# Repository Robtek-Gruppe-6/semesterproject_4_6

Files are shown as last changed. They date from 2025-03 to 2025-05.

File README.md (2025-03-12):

# Control of Pan Tilt System Group 6 (4) ROBTEK Semester 4 SDU
The goal is to control a Pan-Tilt System using an FPGA and a Microcontroller to track heat/IR from an IR emitting moving object.

## FPGA
To setup the FPGA, go to the FPGA folder and check the README.md file there.

## Microcontroller
To setup the Microcontroller, go to the Microcontroller folder and check the README.md file there.
Information about the microcontroller goes here.

## Inventor
To setup Inventor, go to the Inventor folder and check the README.md file there.

## Code explanation

## Resources

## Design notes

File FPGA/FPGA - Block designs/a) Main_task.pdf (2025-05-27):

FPGA_Encoder_handler_1 FPGA_Encoder_handler.bd a

bclk position[14:0] max enrst FPGA_Encoder_handler_2 FPGA_Encoder_handler.bd a bclk position[14:0] max enrst FPGA_Motor_handler_1 FPGA_Motor_handler.bd i[10:0] clk rst o[1:0] en FPGA_Motor_handler_2 FPGA_Motor_handler.bd i[10:0] clk o[1:0] enrst FPGA_SPI_handler_0 FPGA_SPI_handler.bd encoder1[14:0] encoder2[14:0] sck ssmosi enrst miso motor1[10:0] motor2[10:0] clk always_high Constant dout[0:0]

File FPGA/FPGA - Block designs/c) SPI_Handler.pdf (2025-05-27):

encoder2[14:0] clk encoder1[14:0] rst en sckss mosi not_gate_0 not_gate_v1_0 i o encoder_latch2 dlatch_v1_0 clk i[14:0] enrst o[14:0] encoder_latch1 dlatch_v1_0 clk i[14:0] enrst o[14:0] encoder_selctor d_flip_flop_v1_0 clk D Q enrst encoder_selector_mux busmux_2x1_v1_0 input_1[14:0] input_2[14:0] s o[14:0] selector_combine combiner_v1_0 h[0:0] l[14:0] o[15:0] xlconstant_0 Constant dout[0:0] SPI_slave_block cpol cpha sck ssmosi SPI_slave_block_v1_0 miso read_en tx[15:0] rx[15:0] busy rst selector_split i[15:0] n_to_m_splitter_v1_0 o_h[0:0] o_l[10:0] motor_selector busdmux_v1_0 clk endata_in[10:0] sel[0:0] rst data_out_1[10:0] data_out_2[10:0] miso motor1[10:0] motor2[10:0]

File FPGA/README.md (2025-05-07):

# Vivado setup
Use Xilinx Vivado to create a vivado project in this directory.
Name the project "vivado_project", this will make git ignore the project folder, and only update sources and block designs.

Make sure that when you create a new ip/block design, that the file location is the sources or block_design directory. 

Any .bit in this folder are tested binaries ready to be transfered onto the PYNQ-Z2 board

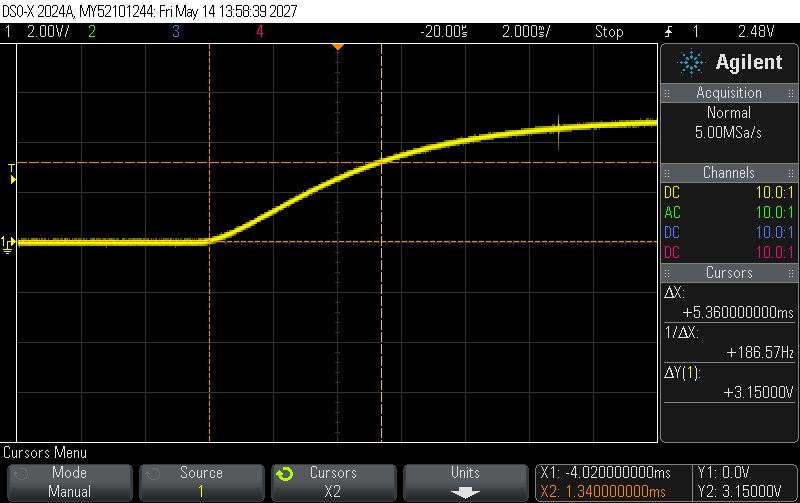
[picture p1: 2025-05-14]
Time_constant_tilt.png

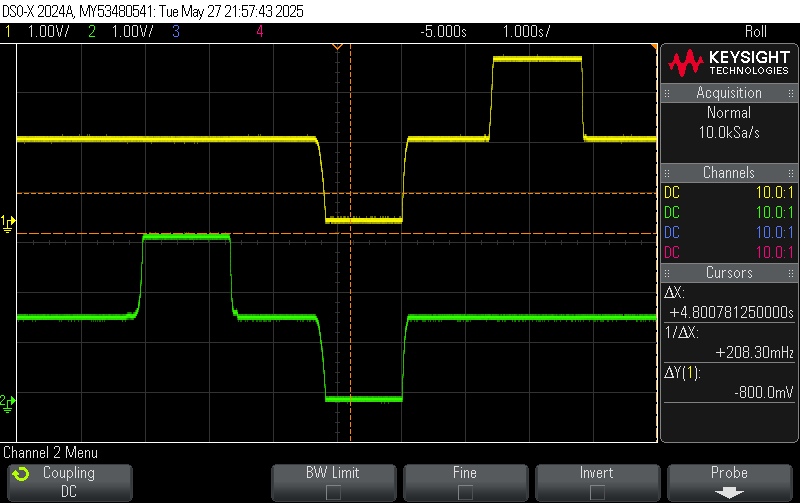
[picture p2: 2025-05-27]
Matlab/oscilloscope/Sensor_circuit.png

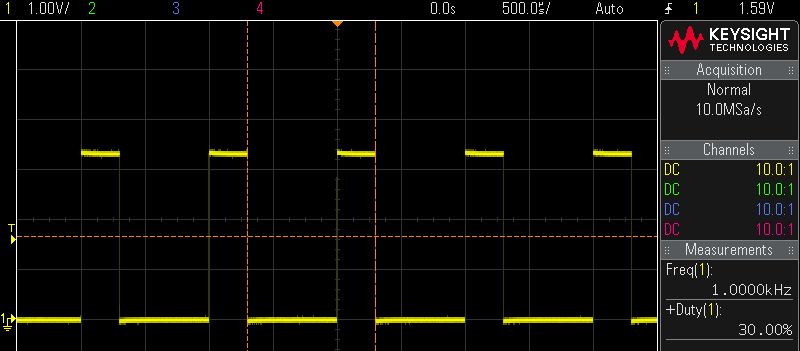
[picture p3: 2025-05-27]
Matlab/oscilloscope/PWM.png

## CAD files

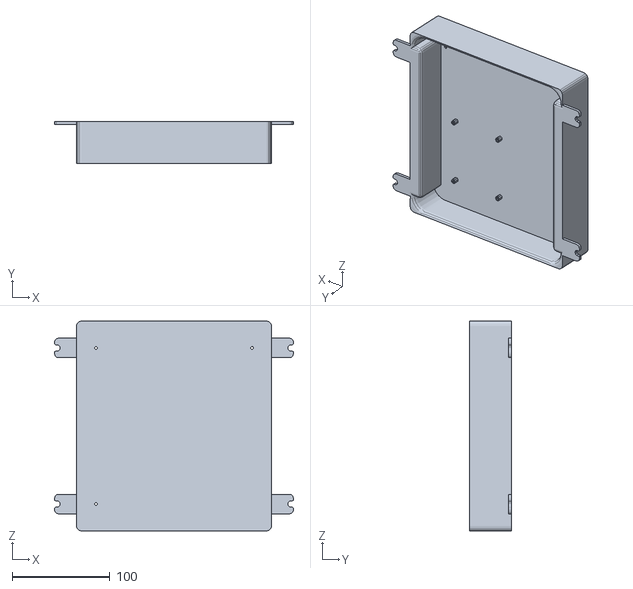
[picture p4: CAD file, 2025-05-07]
Inventor/Infrared_collector.stl
245.0 x 43.0 x 215.0

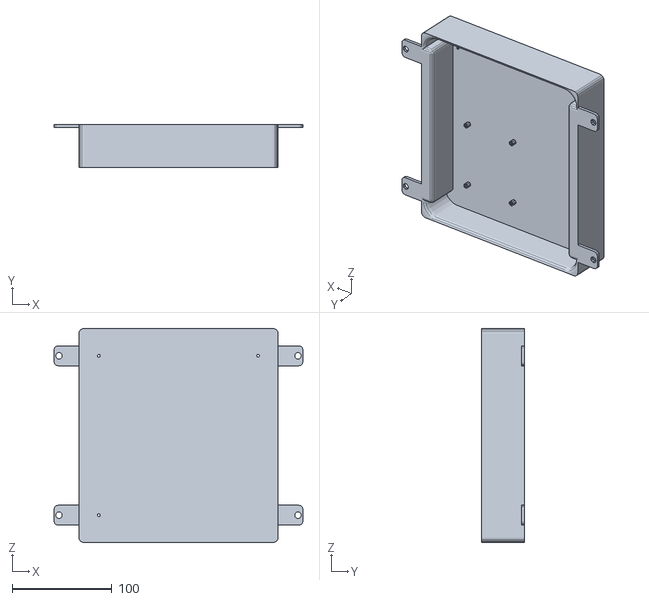
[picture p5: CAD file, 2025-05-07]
Inventor/Infrared_collector_long_ear.stl
250.0 x 43.0 x 215.0

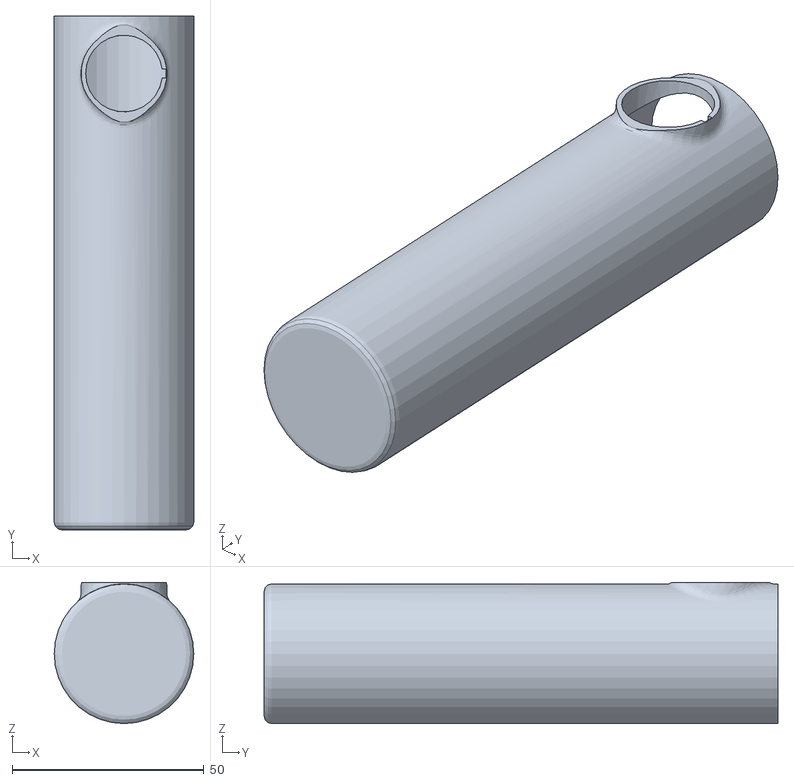
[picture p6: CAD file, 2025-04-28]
Inventor/Flash_light.stl
36.4 x 134.0 x 36.8

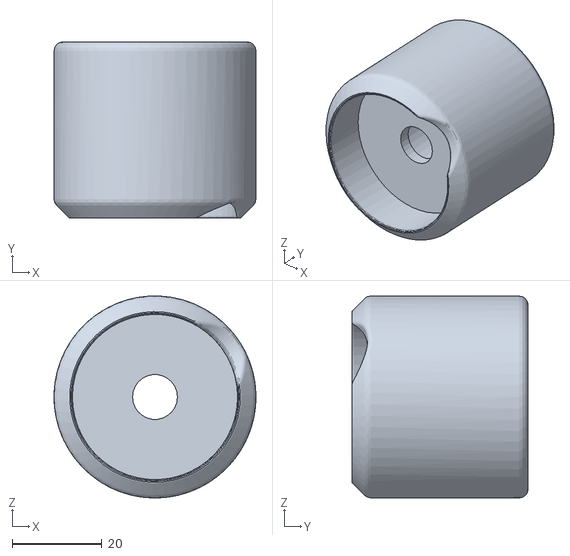
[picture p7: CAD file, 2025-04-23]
Inventor/Flashlight_lid.stl
45.0 x 39.3 x 45.0

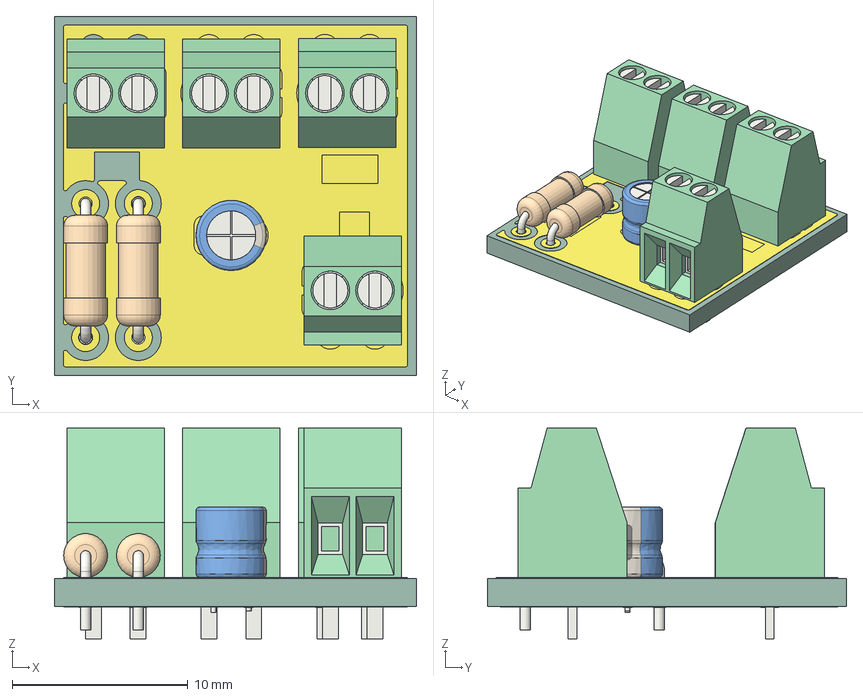
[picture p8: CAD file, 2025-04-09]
Inventor/fleshlight_pcb.step
20.6 x 20.4 x 12.0 mm
R_Axial_DIN0207_L63mm_D25mm_P762mm_Horizontal x 2
TerminalBlock_Phoenix_MPT_05_2_254_1x02_P254mm_Horizontal x 4
CP_Radial_D40mm_P200mm
_autosave-fleshlight_track_1
_autosave-fleshlight_track_2
_autosave-fleshlight_track_3
_autosave-fleshlight_track_4
_autosave-fleshlight_track_5
_autosave-fleshlight_track_6
_autosave-fleshlight_track_7
_autosave-fleshlight_track_8
_autosave-fleshlight_track_9
_autosave-fleshlight_track_10
_autosave-fleshlight_track_11
_autosave-fleshlight_track_12
_autosave-fleshlight_track_13
_autosave-fleshlight_track_14
_autosave-fleshlight_track_15
_autosave-fleshlight_track_16
_autosave-fleshlight_track_17
_autosave-fleshlight_track_18
_autosave-fleshlight_track_19
_autosave-fleshlight_track_20
_autosave-fleshlight_track_21
_autosave-fleshlight_track_22
_autosave-fleshlight_track_23
_autosave-fleshlight_track_24
_autosave-fleshlight_track_25
_autosave-fleshlight_track_26
_autosave-fleshlight_zone_1
_autosave-fleshlight_zone_2
_autosave-fleshlight_pad_1
_autosave-fleshlight_pad_2
_autosave-fleshlight_pad_3
_autosave-fleshlight_pad_4
_autosave-fleshlight_pad_5
_autosave-fleshlight_pad_6
_autosave-fleshlight_pad_7
_autosave-fleshlight_pad_8
_autosave-fleshlight_pad_9
_autosave-fleshlight_pad_10
_autosave-fleshlight_pad_11
_autosave-fleshlight_pad_12
_autosave-fleshlight_pad_13
_autosave-fleshlight_pad_14
_autosave-fleshlight_pad_15
_autosave-fleshlight_pad_16
_autosave-fleshlight_pad_17
_autosave-fleshlight_pad_18
_autosave-fleshlight_pad_19
_autosave-fleshlight_pad_20
_autosave-fleshlight_pad_21
_autosave-fleshlight_pad_22
_autosave-fleshlight_pad_23
_autosave-fleshlight_pad_24
_autosave-fleshlight_pad_25
_autosave-fleshlight_pad_26
_autosave-fleshlight_pad_27
_autosave-fleshlight_pad_28
_autosave-fleshlight_pad_29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

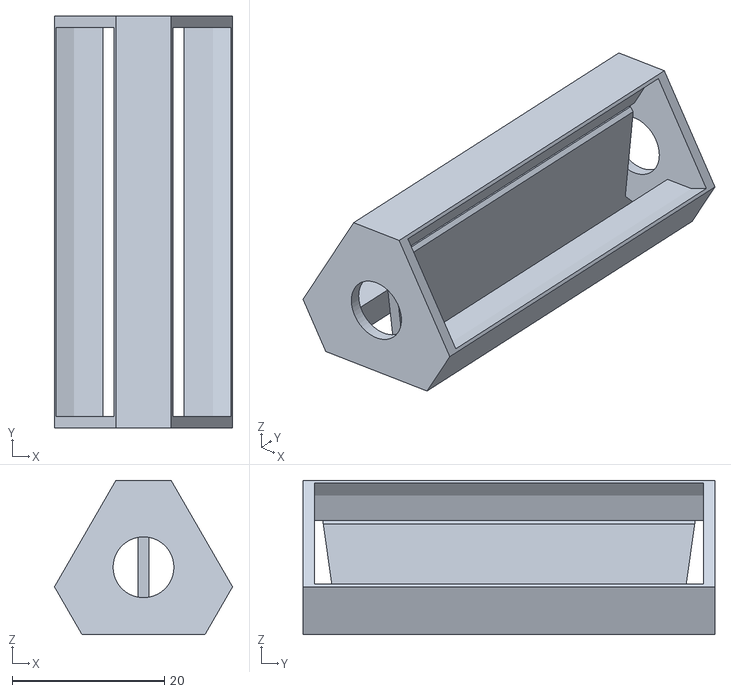
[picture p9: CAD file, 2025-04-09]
Inventor/Battery_Holder_3AA_V1.stl
23.4 x 54.2 x 20.3

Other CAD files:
Inventor/161130345-9-xb-rs601c-1020011bb-zp/xb-rs601c-1020011bb-zp.iam
Inventor/161130345-9-xb-rs601c-1020011bb-zp/xb-rs601c-1020011bb-zp_01.ipt
Inventor/161130345-9-xb-rs601c-1020011bb-zp/xb-rs601c-1020011bb-zp_02.ipt
Inventor/161130345-9-xb-rs601c-1020011bb-zp/xb-rs601c-1020011bb-zp_03.ipt
Inventor/161130345-9-xb-rs601c-1020011bb-zp/xb-rs601c-1020011bb-zp_04.ipt
Inventor/161130345-9-xb-rs601c-1020011bb-zp/xb-rs601c-1020011bb-zp_05.ipt
Inventor/161130345-9-xb-rs601c-1020011bb-zp/xb-rs601c-1020011bb-zp_06.ipt
Inventor/Flash_light.ipt
Inventor/Flashlight.iam
Inventor/Flashlight_lid.ipt
Inventor/Infrared_collector.ipt
Inventor/OldVersions/Flash_light.0004.ipt
Inventor/OldVersions/Flashlight.0006.iam
Inventor/OldVersions/Flashlight_lid.0007.ipt
Inventor/OldVersions/Infrared_collector.0007.ipt
Inventor/fleshlight.ipt
Inventor/fleshlight_pcb/CP_Radial_D4.0mm_P2.00mm.iam
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

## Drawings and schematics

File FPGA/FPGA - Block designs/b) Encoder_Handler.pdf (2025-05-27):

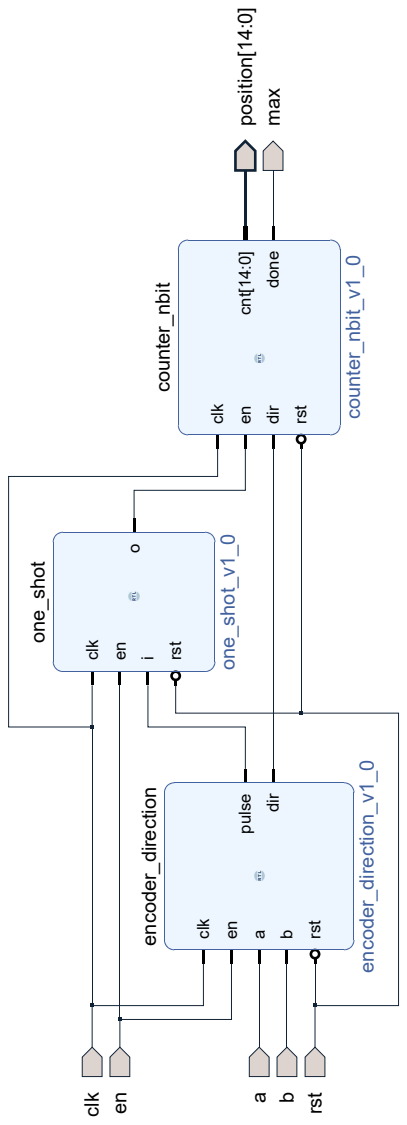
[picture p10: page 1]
clkena; irst

o counter_nbit counter_nbit_v1_0 cnt[14:0] done clk endir rst position[14:0] max

brst pulsedir one_shot one_shot_v1_0 clk en

brst encoder_direction encoder_direction_v1_0 clk en

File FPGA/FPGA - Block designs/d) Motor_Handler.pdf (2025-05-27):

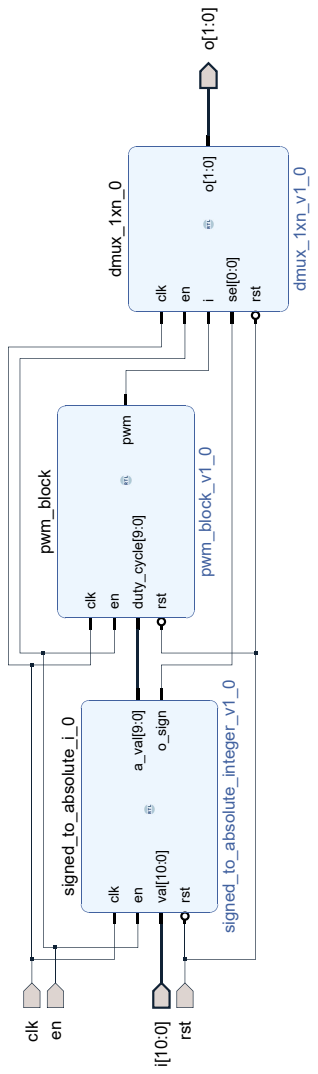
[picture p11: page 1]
isel[0:0] rst o[1:0] o[1:0]

clken i[10:0] rst signed_to_absolute_i_0 signed_to_absolute_integer_v1_0 clk enval[10:0] a_val[9:0] o_sign rst pwm_block pwm_block_v1_0 clk enduty_cycle[9:0] rst pwm dmux_1xn_0 dmux_1xn_v1_0 clk en

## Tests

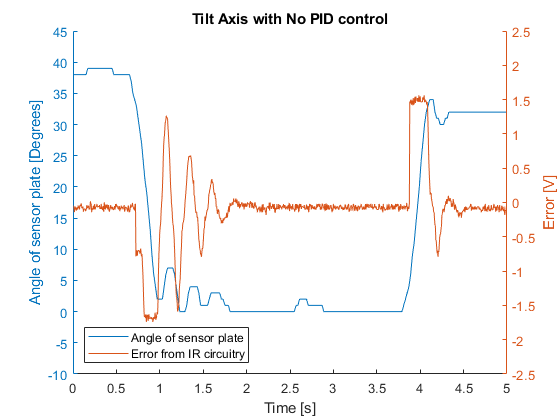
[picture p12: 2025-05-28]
Matlab/pid_tests/tilt_nopid.png

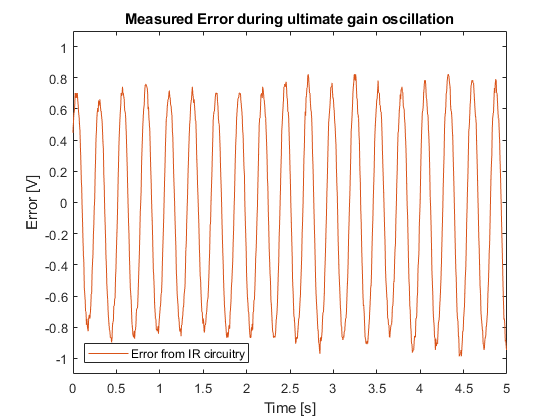
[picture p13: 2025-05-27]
Matlab/pid_tests/ultimate_gain.png

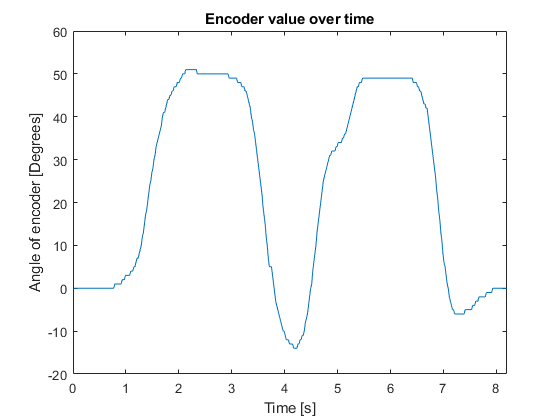
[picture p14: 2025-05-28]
Matlab/pid_tests/encoder_test.png

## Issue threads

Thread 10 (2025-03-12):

Emitterkredsløb

spkki, 2025-03-12:
Magnus laver lommelygte

Svend tegner noget 3d print på et tidspunkt

Emitter kredsløb er ellers done

Lommelygte values:
- Voltage: 4.5V (triple AA battery setup)
- Current: 100mA
- Resistance: 15Ohm

Closed 2025-03-26.

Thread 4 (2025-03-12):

Programmer encoder decoding

spkki, 2025-03-12:

Teh-Faber, 2025-03-19:
Output is represented as degrees per second a fixed point number (Q11.5 number format) where max velocity is 2048 and precision is 6.25% of a degree per second

spkki, 2025-03-19:
We have tested but it doesn't work as there is some kind of problem with dividing in the velocity calculation...

Closed 2025-03-26.

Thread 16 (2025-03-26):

ADC kredsløb

spkki, 2025-03-26:

PapaEchoRomeo, 2025-04-09:
Tested using the led.
Picture 1: When both acd readings are under 1,65 (which is offset to 0) the led is blue.
Picture 2: When one of the adc readings are above 1,65 the led ia purple.
Picture 3: When both adc readings are over 1,65 the led is red.
The adc readings are offset and scaled to return values from -32000 to 32000 :)

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

Closed 2025-05-02.

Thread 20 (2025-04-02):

FPGA arkitektur

spkki, 2025-04-02:

spkki, 2025-04-02:
Vi har lavet motor handler og testet den

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

se 60% duty cycle i en retning og modsat 40% i den anden retning

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

Teh-Faber, 2025-04-09:
SPI Handler finished and integrated into the overall design. Not yet tested

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

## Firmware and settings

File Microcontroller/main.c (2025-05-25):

/*****************************************************************************
 * University of Southern Denmark
 * Embedded C Programming (ECP)
 *
 * MODULENAME.: main.c
 *
 * PROJECT....: SEMESTERPROJECT
 *
 * DESCRIPTION:
 *
 * Change Log:
 ******************************************************************************
 * Date    Id    Change
 * YYMMDD
 * --------------------
 * 250502  SBT    Module created.
 *
 *****************************************************************************/

/***************************** Include files ********************************/
#include <stdint.h>
#include <stdlib.h>
#include "tm4c123gh6pm.h"
#include "emp_type.h"
#include "systick_frt.h"
#include "FreeRTOS.h"
#include "task.h"
#include "queue.h"
#include "semphr.h"

#include "status_led.h"
#include "adc.h"
#include "spi.h"
#include "shared_resources.h"
#include "uart.h"

/*****************************    Defines    ********************************/
#define USERTASK_STACK_SIZE (configMINIMAL_STACK_SIZE * 4) // Increase stack size
#define IDLE_PRIO 0
#define LOW_PRIO 1
#define MED_PRIO 2
#define HIGH_PRIO 3

/*****************************   Constants   ********************************/

/*****************************   Variables   ********************************/

/*****************************   Functions   ********************************/
static void setupHardware(void)
/*****************************************************************************
 *  Input    :  -
 *  Output   :  -
 * *  Function :  Set up the hardware for the project.
 ******************************************************************************/
{
    // Set up the hardware here (GPIO, UART, etc.)
    // Do we need to set up the system clock like in previous project now that it is ignored?
    init_systick();    // Initialize the systick timer
    status_led_init(); // Initialize the status LED
    UART0_Init();
    adc_init(); // Initialize the ADCs
    ADC0_Init();
    SPI0_init(); // Initialize the SPI interface
}

int main(void)
/*****************************************************************************
 * *  Input    :    -
 * *  Output   :    -
 * *  Function :  Main function for the project.
 * ******************************************************************************/
{

    setupHardware(); // Set up the hardware

    TaskResources_t *resources = pvPortMalloc(sizeof(TaskResources_t));

    resources->spi_rx_queue = xQueueCreate(32, sizeof(uint16_t));
    resources->spi_tx_queue = xQueueCreate(32, sizeof(uint16_t));
    resources->adc0_queue = xQueueCreate(32, sizeof(uint16_t));
    resources->adc1_queue = xQueueCreate(32, sizeof(uint16_t));
    resources->spi_mutex = xSemaphoreCreateMutex();

    // xTaskCreate(status_led_task, "Status LED",      USERTASK_STACK_SIZE, (void *) resources, LOW_PRIO, NULL);
    xTaskCreate(adc_task, "ADC Task", USERTASK_STACK_SIZE, (void *)resources, LOW_PRIO, NULL);
    // xTaskCreate(spi_task_read, "SPI Task Read",     USERTASK_STACK_SIZE, (void *) resources, LOW_PRIO, NULL);
    xTaskCreate(spi_task_write, "SPI Task Write", USERTASK_STACK_SIZE, (void *)resources, LOW_PRIO, NULL);
    // xTaskCreate(spi_task_rw, "SPI Task RW",         USERTASK_STACK_SIZE, (void *) resources, LOW_PRIO, NULL);
    // xTaskCreate(SPI_test_task, "SPI Test Task",     USERTASK_STACK_SIZE, (void *) resources, LOW_PRIO, NULL);

    vTaskStartScheduler(); // Start the FreeRTOS scheduler
    // The scheduler should never return, but if it does, we can handle it here
    return 0;
}

/****************************** End Of Module *******************************/

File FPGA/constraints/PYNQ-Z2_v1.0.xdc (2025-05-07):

## This file is a general .xdc for the PYNQ-Z2 board
## To use it in a project:
## - uncomment the lines corresponding to used pins
## - rename the used ports (in each line, after get_ports) according to the top level signal names in the project

## Clock signal 125 MHz

set_property -dict {PACKAGE_PIN H16 IOSTANDARD LVCMOS33} [get_ports clk]
#create_clock -add -name sys_clk_pin -period 8.00 -waveform {0 4} [get_ports { sysclk }];

##Switches

set_property -dict { PACKAGE_PIN M20   IOSTANDARD LVCMOS33 } [get_ports { sw_0 }]; #IO_L7N_T1_AD2N_35 Sch=sw[0]
set_property -dict { PACKAGE_PIN M19   IOSTANDARD LVCMOS33 } [get_ports { sw_1 }]; #IO_L7P_T1_AD2P_35 Sch=sw[1]

##RGB LEDs

#set_property -dict { PACKAGE_PIN L15   IOSTANDARD LVCMOS33 } [get_ports { led4_b }]; #IO_L22N_T3_AD7N_35 Sch=led4_b
#set_property -dict { PACKAGE_PIN G17   IOSTANDARD LVCMOS33 } [get_ports { led4_g }]; #IO_L16P_T2_35 Sch=led4_g
#set_property -dict { PACKAGE_PIN N15   IOSTANDARD LVCMOS33 } [get_ports { led4_r }]; #IO_L21P_T3_DQS_AD14P_35 Sch=led4_r
#set_property -dict { PACKAGE_PIN G14   IOSTANDARD LVCMOS33 } [get_ports { led5_b }]; #IO_0_35 Sch=led5_b
#set_property -dict { PACKAGE_PIN L14   IOSTANDARD LVCMOS33 } [get_ports { led5_g }]; #IO_L22P_T3_AD7P_35 Sch=led5_g
#set_property -dict { PACKAGE_PIN M15   IOSTANDARD LVCMOS33 } [get_ports { led5_r }]; #IO_L23N_T3_35 Sch=led5_r

##LEDs

#set_property -dict { PACKAGE_PIN R14   IOSTANDARD LVCMOS33 } [get_ports { led[0] }]; #IO_L6N_T0_VREF_34 Sch=led[0]
#set_property -dict { PACKAGE_PIN P14   IOSTANDARD LVCMOS33 } [get_ports { led[1] }]; #IO_L6P_T0_34 Sch=led[1]
#set_property -dict { PACKAGE_PIN N16   IOSTANDARD LVCMOS33 } [get_ports { led[2] }]; #IO_L21N_T3_DQS_AD14N_35 Sch=led[2]
#set_property -dict { PACKAGE_PIN M14   IOSTANDARD LVCMOS33 } [get_ports { led[3] }]; #IO_L23P_T3_35 Sch=led[3]

##Buttons

set_property -dict { PACKAGE_PIN D19   IOSTANDARD LVCMOS33 } [get_ports { btn[0] }]; #IO_L4N_T0_35 Sch=btn[1]
set_property -dict { PACKAGE_PIN D20   IOSTANDARD LVCMOS33 } [get_ports { btn[1] }]; #IO_L4N_T0_35 Sch=btn[1]
set_property -dict { PACKAGE_PIN L20   IOSTANDARD LVCMOS33 } [get_ports { btn[2] }]; #IO_L9N_T1_DQS_AD3N_35 Sch=btn[2]
set_property -dict { PACKAGE_PIN L19   IOSTANDARD LVCMOS33 } [get_ports { btn[3] }]; #IO_L9P_T1_DQS_AD3P_35 Sch=btn[3]

##PmodA

#set_property -dict { PACKAGE_PIN Y18   IOSTANDARD LVCMOS33 } [get_ports { hall_index_0 }]; #IO_L17P_T2_34 Sch=ja_p[1]
#set_property -dict { PACKAGE_PIN Y19   IOSTANDARD LVCMOS33 } [get_ports { hall_index_1 }]; #IO_L17N_T2_34 Sch=ja_n[1]
#set_property -dict { PACKAGE_PIN Y16   IOSTANDARD LVCMOS33 } [get_ports { encoder_1b }]; #IO_L7P_T1_34 Sch=ja_p[2]
#set_property -dict { PACKAGE_PIN Y17   IOSTANDARD LVCMOS33 } [get_ports { encoder_1a }]; #IO_L7N_T1_34 Sch=ja_n[2]
#set_property -dict { PACKAGE_PIN U18   IOSTANDARD LVCMOS33 } [get_ports { encoder_2b }]; #IO_L12P_T1_MRCC_34 Sch=ja_p[3]
#set_property -dict { PACKAGE_PIN U19   IOSTANDARD LVCMOS33 } [get_ports { encoder_2a }]; #IO_L12N_T1_MRCC_34 Sch=ja_n[3]
#set_property -dict { PACKAGE_PIN W18   IOSTANDARD LVCMOS33 } [get_ports { ja[6] }]; #IO_L22P_T3_34 Sch=ja_p[4]
#set_property -dict { PACKAGE_PIN W19   IOSTANDARD LVCMOS33 } [get_ports { ja[7] }]; #IO_L22N_T3_34 Sch=ja_n[4]

##PmodB

set_property -dict { PACKAGE_PIN W14   IOSTANDARD LVCMOS33 } [get_ports { motor1[0] }]; #IO_L8P_T1_34 Sch=jb_p[1]
set_property -dict { PACKAGE_PIN Y14   IOSTANDARD LVCMOS33 } [get_ports { motor_en[0] }]; #IO_L8N_T1_34 Sch=jb_n[1]
set_property -dict { PACKAGE_PIN T11   IOSTANDARD LVCMOS33 } [get_ports { motor2[1] }]; #IO_L1P_T0_34 Sch=jb_p[2]
#set_property -dict { PACKAGE_PIN T10   IOSTANDARD LVCMOS33 } [get_ports {  }]; #IO_L1N_T0_34 Sch=jb_n[2]
set_property -dict { PACKAGE_PIN V16   IOSTANDARD LVCMOS33 } [get_ports { motor1[1] }]; #IO_L18P_T2_34 Sch=jb_p[3]
set_property -dict { PACKAGE_PIN W16   IOSTANDARD LVCMOS33 } [get_ports { motor2[0] }]; #IO_L18N_T2_34 Sch=jb_n[3]
set_property -dict { PACKAGE_PIN V12   IOSTANDARD LVCMOS33 } [get_ports { motor_en[1] }]; #IO_L4P_T0_34 Sch=jb_p[4]
#set_property -dict { PACKAGE_PIN W13   IOSTANDARD LVCMOS33 } [get_ports { jb[7] }]; #IO_L4N_T0_34 Sch=jb_n[4]

##Audio

#set_property -dict { PACKAGE_PIN M17   IOSTANDARD LVCMOS33 } [get_ports { adr0 }]; #IO_L8P_T1_AD10P_35 Sch=adr0
#set_property -dict { PACKAGE_PIN M18   IOSTANDARD LVCMOS33 } [get_ports { adr1 }]; #IO_L8N_T1_AD10N_35 Sch=adr1
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

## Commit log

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2025-03-12 First block design
    [design_motor_encoders_motor_encoders_0_0.xml, design_motor_encoders_system_ila_1_0.xml]
2025-03-12 Created VHDL wrapper
    [design_motor_encoders_system_ila_1_0.xml]
2025-03-19 Updated motor encoder block
    Added direction and began velocity calculation.
    [design_motor_encoders_motor_encoders_0_0.xml, design_motor_encoders_sim_clk_gen_0_0.xml, design_motor_encoders_system_ila_1_0.xml]
2025-03-19 Updated motor encoder
    Added multiple new files instead of previously only having one motor encoder file. Combined all the new files into a block design and started testing. Found a issue with scalling.
    [design_motor_encoders_clock_counter_0_0.xml, design_motor_encoders_combiner_0_0.xml, design_motor_encoders_div_gen_0_0.xml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]
2025-03-26 Added ADC tiva microcontroller code
    Added the ADC tiva microcontroller code
2025-03-26 Added electronics circuit
    yup
    [adder-diff-circuit.kicad_sch]
2025-03-26 SPI is worky work
2025-03-26 Functional Encoder and position calculation
    [design_motor_encoders_counter_nbit_0_0.xml, design_motor_encoders_div_gen_0_0.xml, design_motor_encoders_encoder_direction_0_0.xml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]
2025-04-02 Changed structure to handlers
    Removed Eriks shit code and renamed motor encoders block to encoder handler and added two new handlers
    [design_motor_encoders_counter_nbit_0_0.xml, design_motor_encoders_encoder_direction_0_0.xml, design_motor_encoders_one_shot_0_0.xml]
2025-04-02 Motor handler done
    Added constraint file to project and updated it. Motor handler working in simulation. Main task added
    [FPGA_Motor_handler_dmux_1xn_0_0.xml, FPGA_Motor_handler_inst_0_dmux_1xn_0_0.xml, FPGA_Motor_handler_inst_0_pwm_block_0.xml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]
2025-04-02 Made SPI Handler and updated main task
    Made a busdemux as well.
    [FPGA_Motor_handler_inst_0_pwm_block_0.xml, FPGA_Motor_handler_inst_0_signed_to_absolute_i_0_0.xml, FPGA_Motor_handler_inst_1_dmux_1xn_0_0.xml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]
2025-04-02 Update PYNQ-Z2_v1.0.xdc to fix motor pinout
    [PYNQ-Z2_v1.0.xdc]
2025-04-08 Added project files and started design on flashlight
    Added the inventor project files and started making the flashlight design
    [Flash_light.ipt]
2025-04-08 Edited the infrared collector plate
    [Infrared_collector.0001.ipt, Infrared_collector.0002.ipt, Infrared_collector.ipt]
2025-04-09 Spi fpga lagt ind
2025-04-09 doodoo fart
    Added fleshlight
    [fleshlight.ipt]
2025-04-09 Updated FPGA code for SPI Handler
    [FPGA_Motor_handler_dmux_1xn_0_0.xml, FPGA_Motor_handler_pwm_block_0_1.xml, FPGA_Motor_handler_signed_to_absolute_i_0_0.xml]
2025-04-09 Updated flashlight design
    Updated flashlight design
    [Battery_Holder_3AA_V1.stl, Flash_light.0002.ipt, Flash_light.ipt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]
2025-04-09 Updated Flashlight and added lid
    Should be ready for 3d print
    [CP_Radial_D4.0mm_P2.00mm.iam, CP_Radial_D40mm_P200mm.ipt, Flash_light.0002.ipt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]
2025-04-09 Finished SPI Handler
    And integrated into main task. Missing simulation test.
2025-04-10 Fixed SPI TX
    and removed redundant code
2025-04-18 Hurtig tweak rx spi
2025-04-18 Spi rx works skal bare lave en interrupt
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2025-04-23 Updated flashlight
    Updated the flashlight
    [Flash_light.stl, Flashlight.0004.iam, Flashlight.0005.iam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]
2025-04-23 Fixed some things with SPI integration
2025-04-23 Updated flashlight lid and made FPGA home
    Updated the flashlight lidt and created a home function for the FPGA not done yet
    [Flashlight.0005.iam, Flashlight.0006.iam, Flashlight.iam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]
2025-04-23 Home_Handler updated and ready for test + some changes to SPI_Handler
    [FPGA_Motor_handler_inst_0_dmux_1xn_0_0.xml, FPGA_Motor_handler_inst_0_pwm_block_0.xml, FPGA_Motor_handler_inst_0_signed_to_absolute_i_0_0.xml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]
2025-04-28 Updated flashlight
    [Flash_light.0003.ipt, Flash_light.0004.ipt, Flash_light.ipt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]
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2025-05-02 Added adc to the new project and updated main
    Added adc to the new project and made it a task for FreeRTOS also updated the main along with removing the old adc project
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2025-05-02 Added spi and removed old spi
    Added the spi to the new project and made it a task along with removing old code
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2025-05-07 Started UART NOT WORKING
    Started working on UART but it is not working
    [uart.c]
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2025-05-07 UART debugging
    added UART and added it to the ADC task. ready for testing
2025-05-07 Updated infrared collector
    Updated the design and made two stl variants
    [Infrared_collector.0003.ipt, Infrared_collector.0007.ipt, Infrared_collector.ipt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]
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2025-05-07 Main Task Working.
    Der er en bug i Motor_handler med at negativ rotation har den forkerte duty cycle. Altså -25% bliver til 85%
    [FPGA_Main_task_man_auto_motor1_0.xml, FPGA_Motor_handler_inst_0_dmux_1xn_0_0.xml, FPGA_Motor_handler_inst_0_pwm_block_0.xml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]
2025-05-14 Slettet uart og added queues men de er ikke final
    Slettet uart.c og .h og udkommenteret uart_debug i adc. Queues er ikke done men de er declarerede og oprettet
2025-05-14 Sat queus i spi. ADC og SPI virker ikke rigtig dog
2025-05-14 fixed uart and adc_wrapper
    both uart and adc has been fixed and tested.
    [adc.c, main.c, uart.c]
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2025-05-14 Created PID
    Not tested, needs to be turned into a task
2025-05-14 Test kode til SPI udkommenteret
    Aner ikke hvorfor det ikke virker
2025-05-14 Matlab for tranfer function and start of PID
    Matlab for parameter estimation and starting of PID controller and tuning
2025-05-21 added PID files. modified the adc.c file
    the adc may need modifications in terms of the PID usage
2025-05-21 Updated the manual mode
    Updated the manual mode so you can change the pwm in manual
2025-05-22 Spi virker. man skal bare smide ting ind på spi_tx_queue ligesom spi_test_task
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2025-05-22 Updated bit file and fixed motor selection bug
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2025-05-22 updated ADC to fit the frame format
    also updated what was needed in the uart for testing
2025-05-22 ADC to SPI queue
    the ADC task now sends to the SPI queue
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2025-05-26 bunch of oscilloscope stuff
    [scope_rb6_1.csv, scope_rb6_2.csv, scope_rb6_3.csv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]
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2025-05-27 matlab oscilloscope stuff
    [scope_pan_nopid.csv, scope_pan_pid.csv, scope_rb6_1.csv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]
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
